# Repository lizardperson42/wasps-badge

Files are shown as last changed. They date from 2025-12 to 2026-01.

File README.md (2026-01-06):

# wasps-badge

The [WASPS](https://wasp.systems) electronic badge.

## Hardware

CAD files for the hardware are provided in KiCad format in `wasps-badge/`.

### Connectors / Pinout

The badge features three 0.1in-pitch pin headers. Their silkscreen markings
are partially absent or obscured; Pin 1 can be recognized by its square pad.
Their locations are given as in the design files, where the mounting hole is
on top, looking at the front of the board.

| Header | Location | Description |
| --- | --- | --- |
| J1 | Bottom | Flashing connector |
| J2 | Bottom left | CTF breakout |
| J3 | Top right | Shitty Add-On Header |

Pinouts:

| Header | Pin | MCU pin | Description |
| --- | --- | --- | --- |
| J1 | 1 | GND | GND |
| J1 | 2 | VDD | 3.3V |
| J1 | 3 | SWIO / PD1 | SWIO (MCU flashing connection) |
| J1 | 4 | NRST / PD7 | RST (active-low MCU reset) |
| J2 | 1 | GND | GND |
| J2 | 2 | PD0 | "Press me" button (pulled up by MCU) |
| J2 | 3 | PD3 | "Now" LED |
| J2 | 4 | PD5 | "0" LED |
| J2 | 5 | PD6 | "1" LED |
| J3 | 1 (TL) | VDD | 3.3V |
| J3 | 2 (BL) | GND | GND |
| J3 | 3 (TC) | PC2 | I²C SCL line |
| J3 | 4 (BC) | PC1 | I²C SDA line |
| J3 | 5 (TR) | PC3 | GPIO |
| J3 | 6 (BR) | PC4 | GPIO |

On-board-only pinout:

| MCU pin | Description |
| --- | --- |
| NRST / PD7 | "Reset" button |
| PD4 | "Too slow" LED |
| PC6 | Front RGB LEDs (WS2812B, chain length 2) |
| PC7 | Reverse-mounted back RGB LEDs (WS2812B, chain length 3, NRND) |

## Software

A PlatformIO project for a firmware adding basic blinkenlights can be found in
`code/`. Since field testing has indicated that the through-board LEDs are a
little too focused for the intended effect, they are not driven.

The code runs the MCU in a busy loop, limiting battery life. Pull requests to
improve energy efficiency are welcome.

CTF functionality is not included, pull requests welcome.

If you have issues with compiling the firmware, a pre-compiled image is
provided at `code/firmware.bin`. It can be flashed using the tool `rvprog`
like this:

    rvprog -f code/firmware.bin

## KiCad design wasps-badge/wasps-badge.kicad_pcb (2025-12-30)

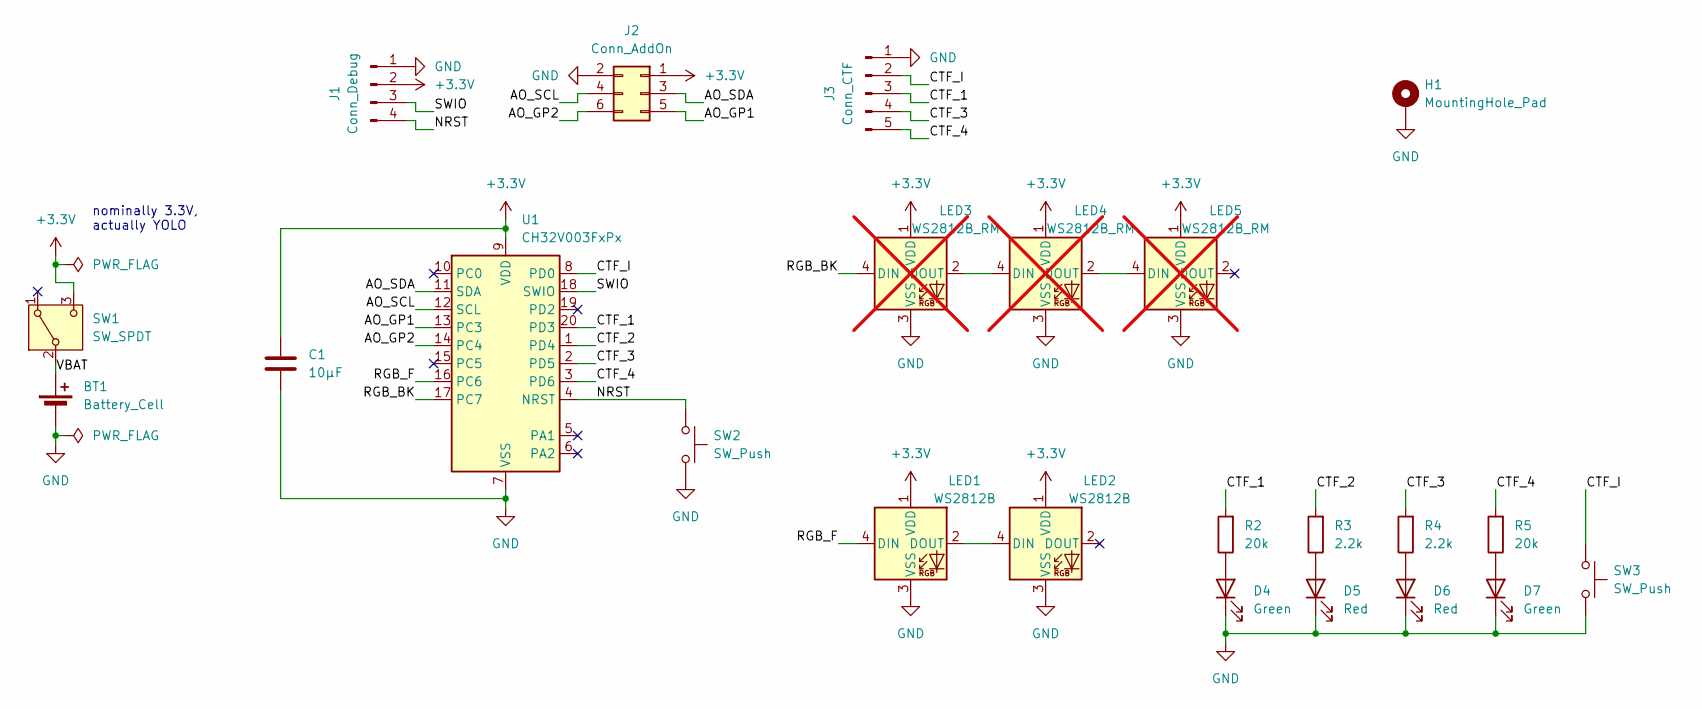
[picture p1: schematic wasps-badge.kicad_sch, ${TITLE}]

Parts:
BT1: Battery_Cell; BatteryHolder_Keystone_1060_1x2032; LCSC C70377
C1: 10µF; C_0603_1608Metric_Pad1.08x0.95mm_HandSolder; LCSC C19702
D4, D7: Green; LED_0603_1608Metric_Pad1.05x0.95mm_HandSolder; LCSC C12624
D5, D6: Red; LED_0603_1608Metric_Pad1.05x0.95mm_HandSolder; LCSC C965799
H1: MountingHole_Pad; MountingHole_3.2mm_M3_Pad
J1: Conn_Debug; PinHeader_1x04_P2.54mm_Vertical
J2: Conn_AddOn; PinSocket_2x03_P2.54mm_Vertical; LCSC C5116527
J3: Conn_CTF; PinHeader_1x05_P2.54mm_Vertical
LED1, LED2: WS2812B; LED_WS2812B_PLCC4_5.0x5.0mm_P3.2mm
LED3, LED4, LED5: WS2812B_RM; LED_WS2812B_Reverse; not fitted
R2, R5: 20k; R_0603_1608Metric_Pad0.98x0.95mm_HandSolder; LCSC C4184
R3, R4: 2.2k; R_0603_1608Metric_Pad0.98x0.95mm_HandSolder; LCSC C4190
SW1: SW_SPDT; SW_SPDT_MSS22D18_SMD; LCSC C41375971
SW2, SW3: SW_Push; SW_PUSH_L4.0-W3.0-LS5.0_SMD; LCSC C5221275
U1: CH32V003FxPx; TSSOP-20_4.4x6.5mm_P0.65mm; LCSC C5187096

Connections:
+3.3V: C1.1, J1.2, J2.1, LED1.1 (VDD), LED2.1 (VDD), LED3.1 (VDD), LED4.1 (VDD), LED5.1 (VDD), SW1.3 (C), U1.9 (VDD)
/AO_GP1: J2.5, U1.13 (PC3)
/AO_GP2: J2.6, U1.14 (PC4)
/AO_SCL: J2.4, U1.12 (SCL)
/AO_SDA: J2.3, U1.11 (SDA)
/CTF_1: J3.3, R2.2, U1.20 (PD3)
/CTF_2: R3.2, U1.1 (PD4)
/CTF_3: J3.4, R4.2, U1.2 (PD5)
/CTF_4: J3.5, R5.2, U1.3 (PD6)
/CTF_I: J3.2, SW3.1, U1.8 (PD0)
/NRST: J1.4, SW2.1, U1.4 (NRST)
/RGB_BK: LED3.4 (DIN), U1.17 (PC7)
/RGB_F: LED1.4 (DIN), U1.16 (PC6)
/SWIO: J1.3, U1.18 (SWIO)
/VBAT: BT1.1 (+), SW1.2 (B)
GND: BT1.2 (-), C1.2, D4.1 (K), D5.1 (K), D6.1 (K), D7.1 (K), H1.1, J1.1, J2.2, J3.1, LED1.3 (VSS), LED2.3 (VSS), LED3.3 (VSS), LED4.3 (VSS), LED5.3 (VSS), SW2.2, SW3.2, U1.7 (VSS)
unnamed: D4.2 (A), R2.1
unnamed: D5.2 (A), R3.1
unnamed: D6.2 (A), R4.1
unnamed: D7.2 (A), R5.1
unnamed: LED1.2 (DOUT), LED2.4 (DIN)
unnamed: LED3.2 (DOUT), LED4.4 (DIN)
unnamed: LED4.2 (DOUT), LED5.4 (DIN)

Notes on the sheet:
nominally 3.3V, actually YOLO

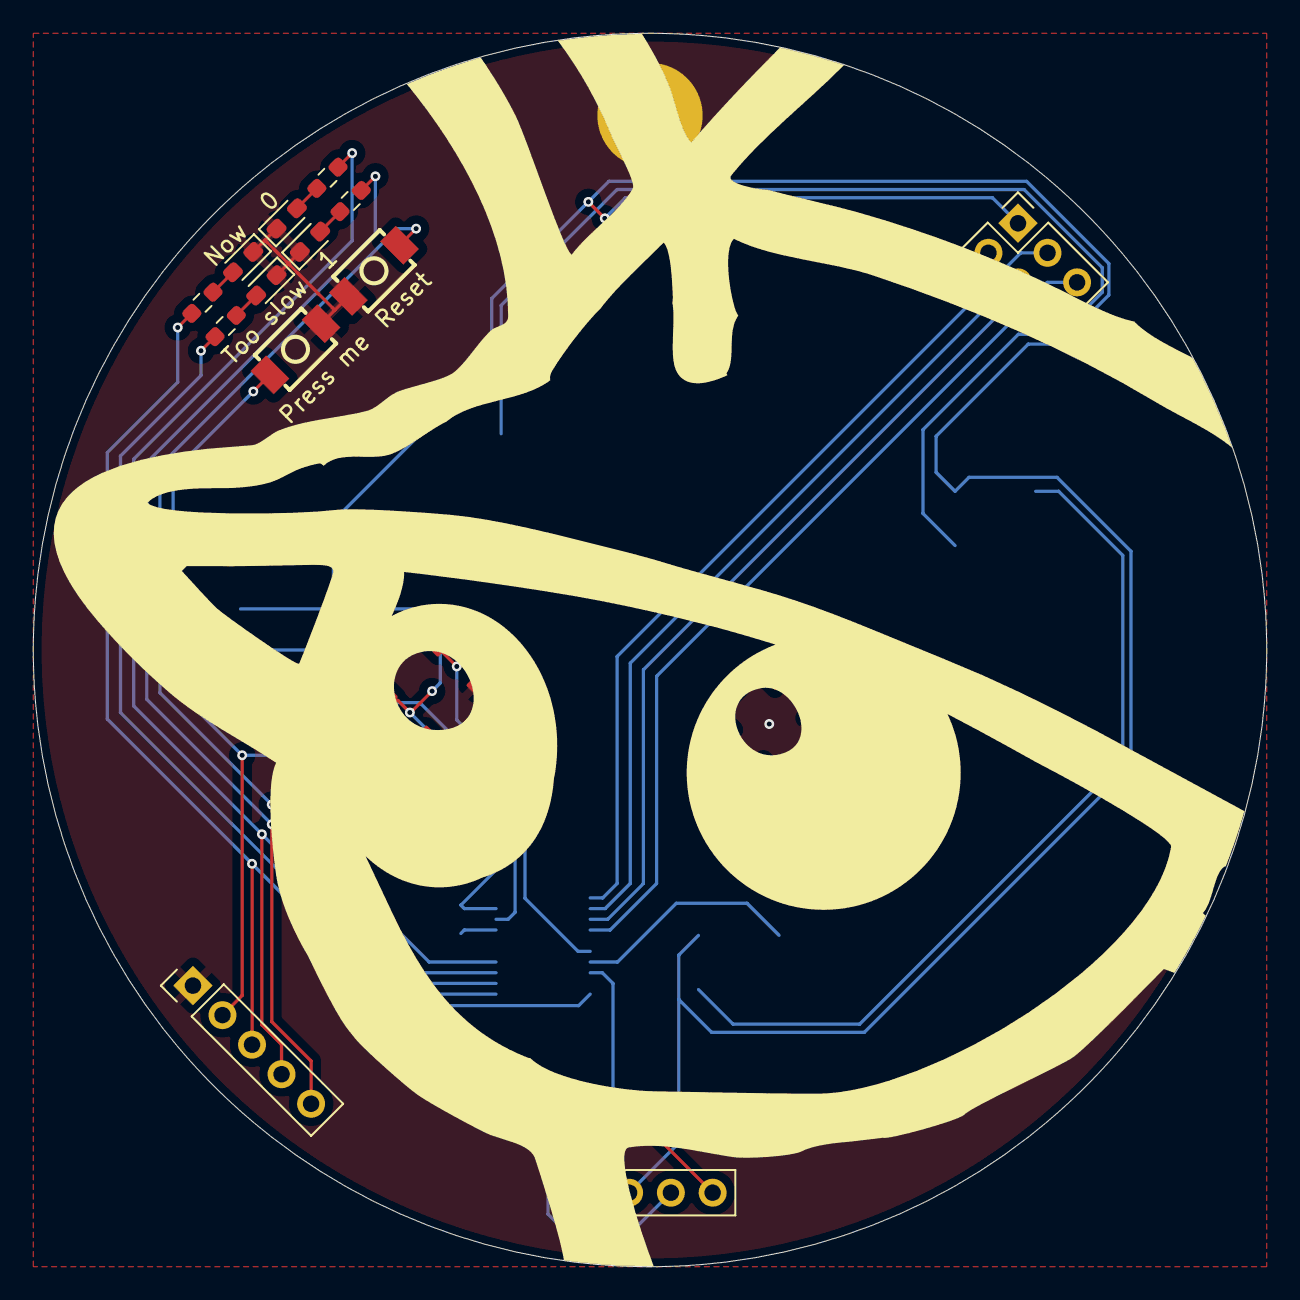
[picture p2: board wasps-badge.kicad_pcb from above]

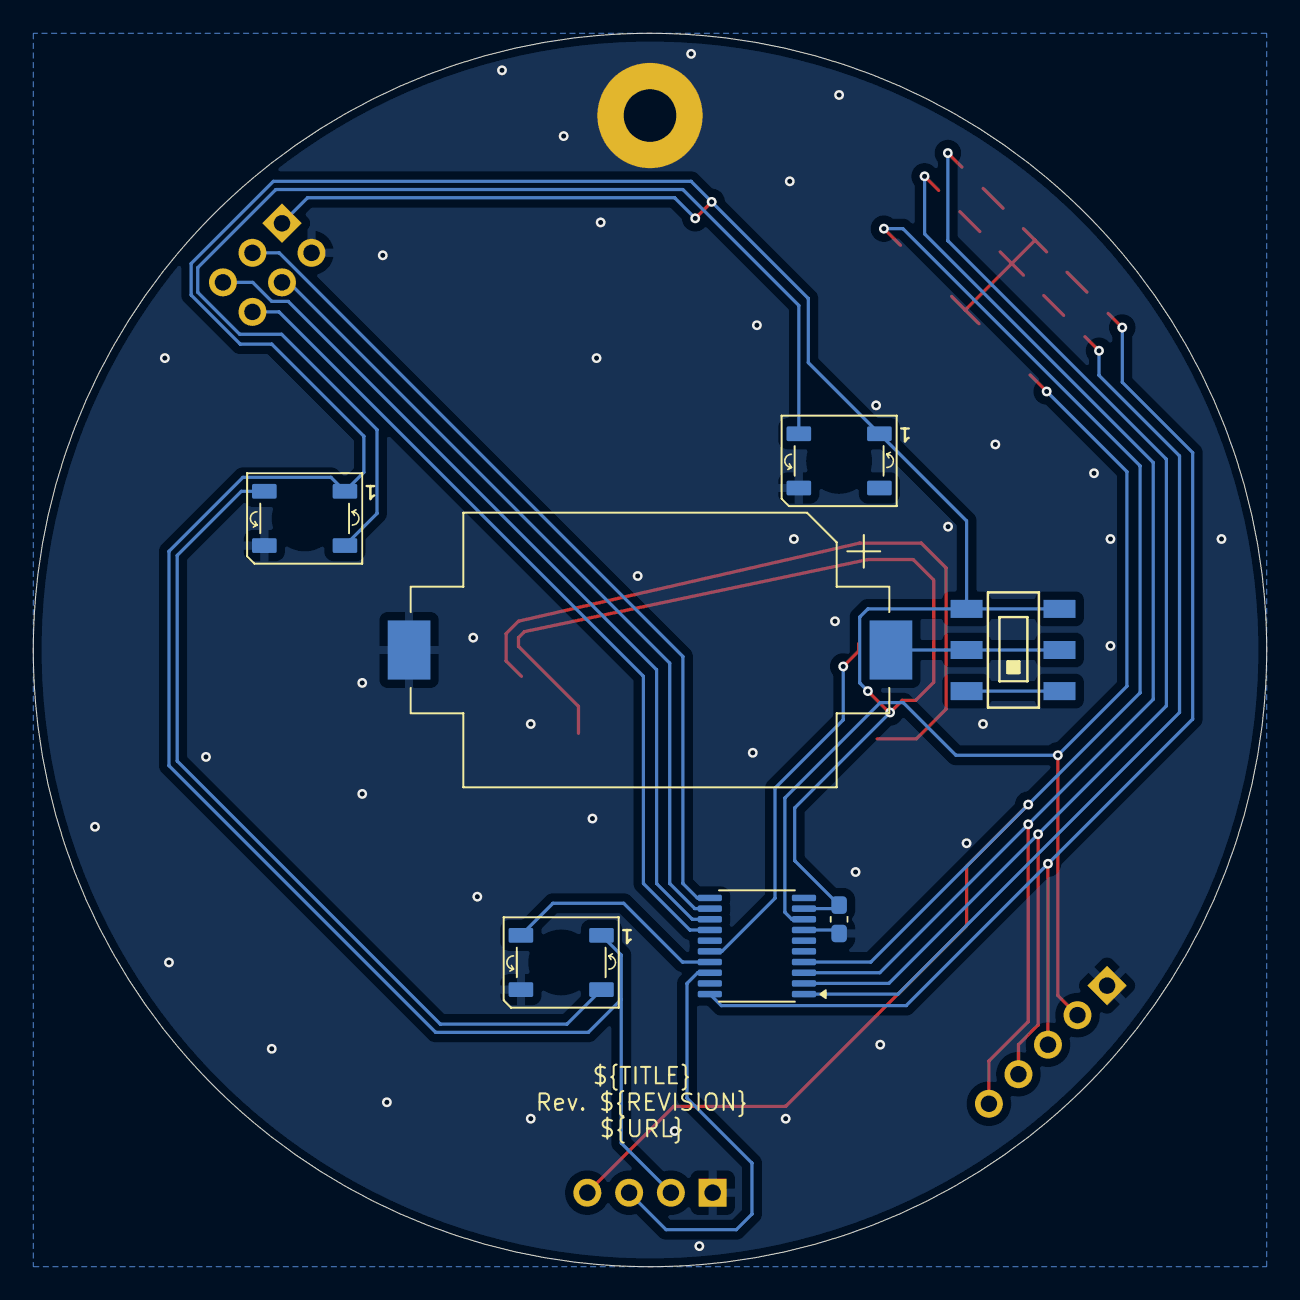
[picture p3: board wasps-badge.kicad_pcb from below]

Board: 2 copper layers, 75.0 x 75.0 mm, 24 parts (7 on the bottom side), 23 nets.

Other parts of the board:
BOARD: WaspFace

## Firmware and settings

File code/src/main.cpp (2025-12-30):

#include <Arduino.h>

#include "ws2812.h"

struct FineHSV {
    uint16_t hue;
    uint8_t saturation;
    uint8_t value;

    static constexpr uint16_t MAX_HUE = 256 * 6;

    FineHSV(uint16_t hue, uint8_t saturation, uint8_t value) :
        hue(hue), saturation(saturation), value(value) {}

    operator Color() const {
        // <https://en.wikipedia.org/wiki/HSL_and_HSV#HSV_to_RGB>
        int chroma = value * saturation / 255;
        int complement = hue % (2 * 256);
        if (complement >= 256) complement = 512 - complement;
        complement = complement * chroma / 256;

        int r, g, b;
        if (hue < 256) {
            r = chroma    ; g = complement; b = 0         ;
        } else if (hue < 256 * 2) {
            r = complement; g = chroma    ; b = 0         ;
        } else if (hue < 256 * 3) {
            r = 0         ; g = chroma    ; b = complement;
        } else if (hue < 256 * 4) {
            r = 0         ; g = complement; b = chroma    ;
        } else if (hue < 256 * 5) {
            r = complement; g = 0         ; b = chroma    ;
        } else {
            r = chroma    ; g = 0         ; b = complement;
        }

        int whiten = value - chroma;
        return Color{ uint8_t(r + whiten),
                      uint8_t(g + whiten),
                      uint8_t(b + whiten) };
    }
};

class RainbowGenerator {
    Color &_output;
    uint16_t _counter;
    uint16_t _step;
    uint8_t _saturation;
    uint8_t _value;

public:
    RainbowGenerator(Color &output, uint16_t step,
                     uint8_t saturation, uint8_t value) :
        _output(output), _counter(0), _step(step),
        _saturation(saturation), _value(value) {}

    void step() {
        _output = FineHSV(_counter, _saturation, _value);
        _counter += _step;
        _counter %= FineHSV::MAX_HUE;
    }
};

#define PIN_LED_NOW   PD3
#define PIN_LED_2SLOW PD4
#define PIN_LED_0     PD5
#define PIN_LED_1     PD6

#define PIN_RGB_FRONT PC6
#define PIN_RGB_BACK  PC7

#define PIN_BUTTON    PD0

const int PINS[] = { PIN_LED_NOW, PIN_LED_0, PIN_LED_1, PIN_LED_2SLOW };

volatile unsigned counter = 0;

Color colors_front[2] = {};
WS2812 output_front(colors_front, { GPIOC, 6 });

RainbowGenerator rainbow[] = {
    { colors_front[0], FineHSV::MAX_HUE / 8 / 10, 255, 8 },
    { colors_front[1], FineHSV::MAX_HUE / 8 / 7, 255, 8 }
};

void resetCounter() {
    counter = 0;
}

void setup() {
    for (int pin : PINS) pinMode(pin, OUTPUT);
    pinMode(PIN_RGB_FRONT, OUTPUT);
    pinMode(PIN_BUTTON, INPUT_PULLUP);
    // The CH32V003 framework does not use the normal Arduino API. :(
    attachInterrupt(digitalPinToInterrupt(PIN_BUTTON), GPIO_Mode_IPU,
                    resetCounter, EXTI_Mode_Interrupt, EXTI_Trigger_Falling);
}

void loop() {
    unsigned curCounter = counter;
    if (curCounter < 8 * 5) {
        digitalWrite(PINS[curCounter & 3], !(curCounter >> 2 & 1));
        counter = curCounter + 1;
    }
    for (auto &r : rainbow) r.step();
    output_front.output();
    delay(125);
}

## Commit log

2025-12-13 Import project state
    [wasps-badge.kicad_pcb, wasps-badge.kicad_sch]
2025-12-13 Add missing footprint assignments
    [wasps-badge.kicad_sch]
2025-12-13 Change mounting hole pad name
    The footprint calls it "1", so "1" it is.
    [wasps-badge.kicad_sch]
2025-12-13 Add cursed reverse-mounted RGB LED footprint
2025-12-15 First routing attempt; drop MISC header
    [wasps-badge.kicad_pcb, wasps-badge.kicad_sch]
2025-12-15 Fix CTF header position
    [wasps-badge.kicad_pcb]
2025-12-15 Add labeling
    [wasps-badge.kicad_pcb, wasps-badge.kicad_sch]
2025-12-15 Add more vias
    [wasps-badge.kicad_pcb]
2025-12-15 Update reverse-mount LED footprints
    Does this actually *do* anything?..
    [wasps-badge.kicad_pcb]
2025-12-15 Define resistor values
    [wasps-badge.kicad_pcb, wasps-badge.kicad_sch]
2025-12-16 Tweak LED5 location
    Maybe placing a raised ground pin close to... any of the battery's
    contacts is not *that* good an idea.
    [wasps-badge.kicad_pcb]
2025-12-16 Add supplier part numbers
    [wasps-badge.kicad_pcb, wasps-badge.kicad_sch]
2025-12-16 Adjust BOM settings
2025-12-28 Add RGB LED driving
2025-12-28 Drop back LEDs
    They *do* work, but not all that well.
2025-12-28 Add non-RGB LED animation time limit
2025-12-30 Remove reverse-mount LEDs from BOM and placement
    [wasps-badge.kicad_pcb, wasps-badge.kicad_sch]
2025-12-30 Fix firmware.bin file permissions
    Unless CH32 microcontrollers get a *lot* more powerful, it is unlikely
    that the file will be natively executable whereever it is checked out.
2026-02-20 switch to python:3.14, change target name and remove bash -c
